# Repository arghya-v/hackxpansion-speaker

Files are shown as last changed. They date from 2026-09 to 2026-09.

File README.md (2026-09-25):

# hackxpansion Speaker Module

**Crates:** pkg:cargo/hackxpansion_speaker@0.1.0
<br/>
A speaker module for hackxpansion that allows sound to be emitted from the device

The module takes digital audio from the Hackxpansion controller, converts it to an analog signal, amplifies it, and drives a speaker
## Images
case
pcb

## Schematic
schematic
## Overview

The Speaker Module provides the HackXpansion system with a dedicated audio output.

```text
                    Hackxpansion Controller
                              │
                              │
                    ┌─────────┴─────────┐
                    │    Digital Audio  │
                    │                   │
                    └─────────┬─────────┘
                              │
                              ▼
                    ┌───────────────────┐
                    │  TLV320DAC3100    │
                    │    Audio DAC      │
                    └─────────┬─────────┘
                              │
                              │ Analog Audio
                              ▼
                    ┌───────────────────┐
                    │      PAM8320      │
                    │  Class-D Amplifier│
                    └─────────┬─────────┘
                              │
                              ▼
                         ┌─────────┐
                         │ Speaker │
                         └─────────┘
```

The controller sends digital audio to the module over I²S. The TLV320DAC3100 converts the digital signal into analog audio, which is then amplified by the PAM8320 before being sent to the speaker.

## Features
* 48 kHz, 16-bit audio
* Two user-input buttons

## Hardware

The **TLV320DAC3100** converts the incoming digital I²S stream into an analog audio signal.

It is configured for:

```text
Sample Rate: 48 kHz
Bit Depth:   16-bit
Interface:   I²S
MCLK:        12.288 MHz
```

The DAC is controlled over I²C and has a dedicated hardware reset line.

The analog output from the DAC is passed to a **PAM8320 Class-D amplifier**.

## Module Interface

The module uses the HackXpansion GPIO bank for both audio and user input.

| GPIO  | Function  |
| ----- | --- |
| GPIO0 | I²C SCL |
| GPIO1 | I²C SDA |
| GPIO2 | I²S BCLK  |
| GPIO3 | I²S DIN |
| GPIO4 | I²S LRCLK |
| GPIO5 | MCLK |
| GPIO6 | DAC RESET |
| GPIO7 | Button 1  |
| GPIO8 | Button 2  |
| GPIO9 | Unused |

See the [Xpanse API docs](https://docs.rs/xpanse-api/latest/xpanse_api/index.html)

This allows the main HackXpansion firmware to assign functionality to the buttons without the speaker module needing to know what those actions are.

The driver is responsible for:

1. Resetting the audio DAC
2. Configuring the DAC over I²C
3. Starting the master clock
4. Starting the I²S output
5. Registering the audio interface with HackXpansion
6. Registering the module buttons

`lib.rs` contains the HackXpansion-specific module driver, while `dac.rs` contains the reusable TLV320DAC3100 driver.

---

This was all possible thanks to [Hackspansion: A hackclub YSWS](http://hackxpansion.hackclub.com/)

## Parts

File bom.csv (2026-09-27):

Designator | Footprint | Quantity | Value | LCSC Part #
C1 | C155422_C0402 | 1 | 100nF | C155422
C2, C3, C4, C5, C7 | C15850_C0805 | 5 | 10 µF | C15850
J1 | Male_Module | 1 | ~
LS1 | SPKR_CMS-15113-078S | 1 | CMS-15113-078S
R1 | 0805 | 1 | 1k
R2 | 0805 | 1 | 68k
R3, R4 | 0805 | 2 | 10k
SW1, SW2 | SW_PUSH_6mm | 2 | SW_Push
U1 | C179677_LFCSP-32_L5_0-W5_0-P0_50-BL-EP | 1 | TLV320DAC3100IRHBR | C179677
U2 | C113367_MSOP-8_L3_0-W3_0-P0_65-LS5_0-BL | 1 | PAM8302AASCR | C113367

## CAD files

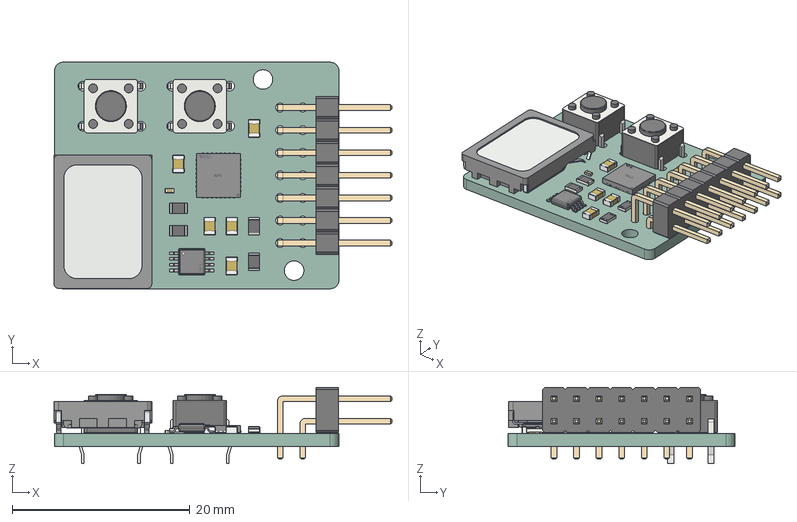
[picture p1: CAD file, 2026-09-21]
Bluetooth Mod.step
38.0 x 25.5 x 8.58 mm
C0805_L2.0-W1.3-H1.3 x 5
CUI_DEVICES_CMS-15113-078S
C0402_L1.0-W0.5-H0.5
R_0805_2012Metric x 4
PinHeader_2x07_P254mm_Horizontal
MSOP-8_L3.0-W3.0-P0.65-LS5.0-BL
LFCSP-32_L5.0-W5.0-H0.8-P0.50
SW_PUSH_6mm x 2
BluDF65_PCB

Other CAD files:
speaker module.f3z

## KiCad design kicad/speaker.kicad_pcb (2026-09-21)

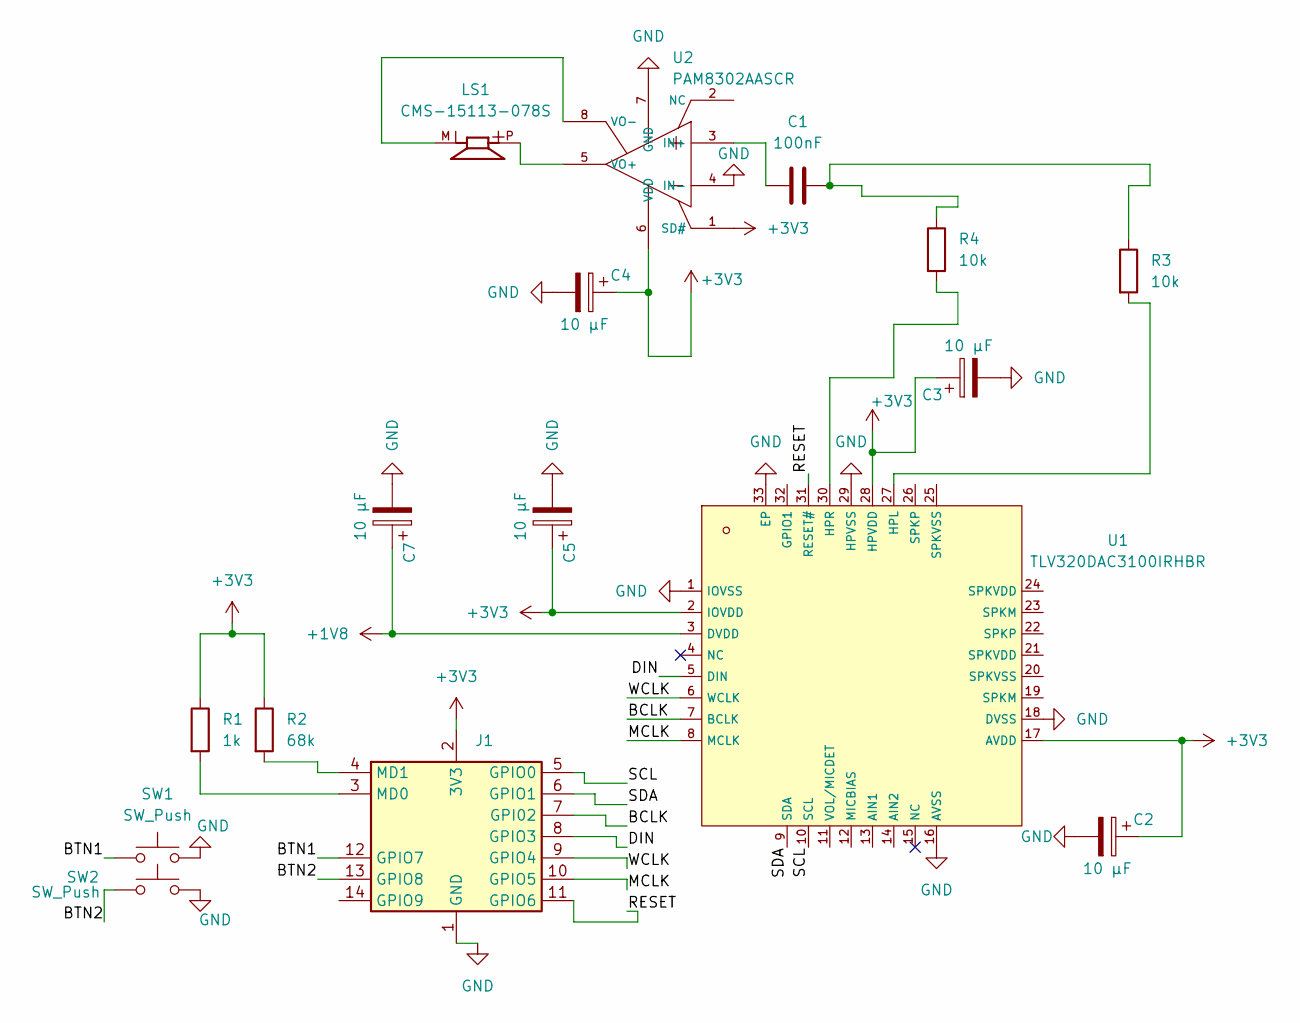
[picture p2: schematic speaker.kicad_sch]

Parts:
C1: 100nF; C155422_C0402
C2, C3, C4, C5, C7: 10 µF; C15850_C0805
J1: Male_Module
LS1: CMS-15113-078S; SPKR_CMS-15113-078S; PARTREV 1
R1: 1k; R_0805_2012Metric_Pad1.20x1.40mm_HandSolder
R2: 68k; R_0805_2012Metric_Pad1.20x1.40mm_HandSolder
R3, R4: 10k; R_0805_2012Metric_Pad1.20x1.40mm_HandSolder
SW1, SW2: SW_Push; SW_PUSH_6mm
U1: TLV320DAC3100IRHBR; C179677_LFCSP-32_L5_0-W5_0-P0_50-BL-EP; LCSC C179677
U2: PAM8302AASCR; C113367_MSOP-8_L3_0-W3_0-P0_65-LS5_0-BL; LCSC C113367

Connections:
+1V8: C7.1, U1.3 (DVDD)
+3V3: C2.1, C3.1, C4.1, C5.1, J1.2 (3V3), R1.1, R2.1, U1.2 (IOVDD), U1.17 (AVDD), U1.28 (HPVDD), U2.1 (SD#), U2.6 (VDD)
/BCLK: J1.7 (GPI02), U1.7 (BCLK)
/BTN1: J1.12 (GPIO7), SW1.1
/BTN2: J1.13 (GPIO8), SW2.1
/DIN: J1.8 (GPIO3), U1.5 (DIN)
/MCLK: J1.10 (GPIO5), U1.8 (MCLK)
/RESET: J1.11 (GPIO6), U1.31 (RESET#)
/SCL: J1.5 (GPIO0), U1.10 (SCL)
/SDA: J1.6 (GPIO1), U1.9 (SDA)
/WCLK: J1.9 (GPIO4), U1.6 (WCLK)
GND: C2.2, C3.2, C4.2, C5.2, C7.2, J1.1 (GND), SW1.2, SW2.2, U1.1 (IOVSS), U1.16 (AVSS), U1.18 (DVSS), U1.29 (HPVSS), U1.33 (EP), U2.4 (IN-), U2.7 (GND)
unnamed: C1.2, R3.1, R4.1
unnamed: J1.3 (MD0), R1.2
unnamed: J1.4 (MD1), R2.2
unnamed: R3.2, U1.27 (HPL)
unnamed: R4.2, U1.30 (HPR)
unnamed: C1.1, U2.3 (IN+)
unnamed: LS1.P, U2.5 (VO+)
unnamed: LS1.M, U2.8 (VO-)

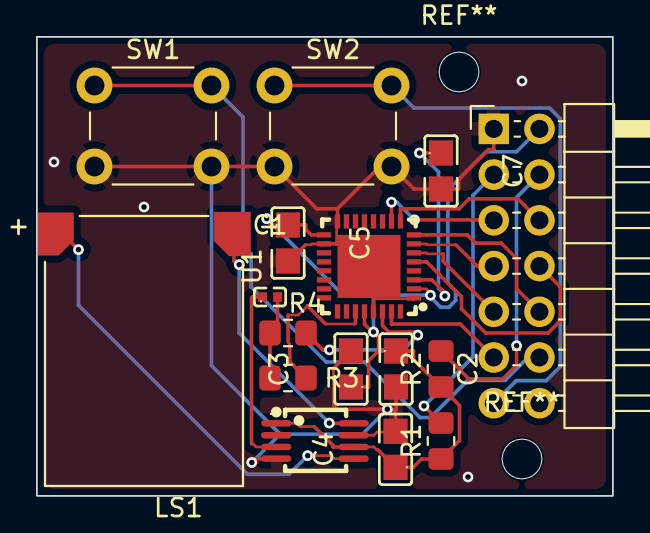
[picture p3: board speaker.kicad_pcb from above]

Board: 2 copper layers, 32.0 x 25.5 mm, 16 parts (0 on the bottom side), 20 nets.

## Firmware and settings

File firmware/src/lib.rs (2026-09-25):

#![no_std]

pub mod dac;

use embassy_rp::{
    dma,
    gpio::{Level, Output},
    interrupt::typelevel::{Binding, DMA_IRQ_0},
    peripherals::DMA_CH0,
    pio_programs::{
        clk::{PioClk, PioClkProgram},
        i2s::{PioI2sOut, PioI2sOutProgram},
    },
};

use xpanse_api::{
    with_pio,
    bus::allocator::BusAllocator,
    driver::{Driver, DriverError, DriverMeta},
    gpio_bank::{BankPins, GpioBank},
    interfaces::buttons::{
        pin_button,
        A,
        B,
    },
    metadata::{
        ModuleDetectResistor,
        ModuleID,
        ModuleSlot,
    },
    registry::Registry,
};

const SAMPLE_RATE: u32 = 48_000;
const BIT_DEPTH: u32 = 16;
const MCLK_FREQUENCY: u32 = 12_288_000;

#[derive(Copy, Clone)]
pub struct AudioDmaIrqs;

unsafe impl Binding<DMA_IRQ_0, dma::InterruptHandler<DMA_CH0>> for AudioDmaIrqs {}

pub struct SpeakerDriver;

impl DriverMeta for SpeakerDriver {
    const ID: ModuleID = ModuleID {
        md0: ModuleDetectResistor::R1K,
        md1: ModuleDetectResistor::R68K,
    };
}

impl<G> Driver<G> for SpeakerDriver
where
    G: BankPins,
{
    async fn create(
        bank: GpioBank<G>,
        slot: ModuleSlot,
        registry: &mut Registry,
        buses: &mut BusAllocator,
    ) -> Result<(), DriverError> {

        let mut reset = Output::new(
            bank.gpio6,
            Level::Low,
        );

        embassy_time::Timer::after_millis(5).await;

        reset.set_high();

        embassy_time::Timer::after_millis(10).await;

        core::mem::forget(reset);

        let mut i2c_bus = buses
            .create_i2c_bitbang(
                bank.gpio0,
                bank.gpio1,
                400_000,
            )
            .map_err(|_| DriverError::InitFailed)?;

        dac::reset(&mut i2c_bus).await?;

        dac::configure(&mut i2c_bus).await?;

        registry.register(
            slot,
            Self::ID,
            pin_button::<A>(
                bank.gpio7.into(),
            ),
        );

        registry.register(
            slot,
            Self::ID,
            pin_button::<B>(
                bank.gpio8.into(),
            ),
        );

        let dma = buses
            .request_dma::<DMA_CH0>()
            .map_err(|_| DriverError::InitFailed)?;

        let mclk_pio = buses
            .request_pio(&[
                &bank.gpio5,
            ])
            .ok_or(DriverError::InitFailed)?;

        with_pio!(
            mclk_pio,
            mclk_common,
            mclk_sm,
            {
                let mclk_program = PioClkProgram::new(
                    &mut *mclk_common,
                );

                let mut mclk = PioClk::new(
                    &mut *mclk_common,
                    mclk_sm,
                    bank.gpio5,
                    &mclk_program,
                    MCLK_FREQUENCY,
                );

                mclk.start();

                core::mem::forget(mclk);
            }
        );

        let i2s_pio = buses
            .request_pio(&[
                &bank.gpio2,
                &bank.gpio3,
                &bank.gpio4,
            ])
            .ok_or(DriverError::InitFailed)?;

        with_pio!(
            i2s_pio,
            i2s_common,
            i2s_sm,
            {
                let i2s_program = PioI2sOutProgram::new(
                    &mut *i2s_common,
                );

                let mut i2s = PioI2sOut::new(
                    &mut *i2s_common,
                    i2s_sm,
                    dma,
                    AudioDmaIrqs,
                    bank.gpio3,
                    bank.gpio2,
                    bank.gpio4,
                    SAMPLE_RATE,
                    BIT_DEPTH,
                    &i2s_program,
                );

                i2s.start();

                registry.register(
                    slot,
                    Self::ID,
                    i2s,
                );
            }
        );

        Ok(())
    }
}

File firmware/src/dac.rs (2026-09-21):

use embassy_time::Timer;
use embedded_hal_async::i2c::I2c;

use xpanse_api::driver::DriverError;

const DAC_ADDRESS: u8 = 0x18;

async fn write_register<I>(
    i2c: &mut I,
    register: u8,
    value: u8,
) -> Result<(), DriverError>
where
    I: I2c,
{
    i2c.write(
        DAC_ADDRESS,
        &[register, value],
    )
    .await
    .map_err(|_| DriverError::InitFailed)
}

pub async fn reset<I>(
    i2c: &mut I,
) -> Result<(), DriverError>
where
    I: I2c,
{
    write_register(i2c, 0x00, 0x00).await?;

    write_register(i2c, 0x01, 0x01).await?;

    Timer::after_millis(10).await;

    Ok(())
}

pub async fn configure<I>(
    i2c: &mut I,
) -> Result<(), DriverError>
where
    I: I2c,
{
    
    write_register(i2c, 0x00, 0x00).await?;
    write_register(i2c, 0x04, 0x00).await?;
    // NDAC = 1, powered
    write_register(i2c, 0x0B, 0x81).await?;
    // MDAC = 2, powered
    write_register(i2c, 0x0C, 0x82).await?;
    // DOSR = 128
    write_register(i2c, 0x0D, 0x00).await?;
    write_register(i2c, 0x0E, 0x80).await?;
    write_register(i2c, 0x1B, 0x00).await?;
    write_register(i2c, 0x1C, 0x00).await?;
    write_register(i2c, 0x3C, 0x0B).await?;
    write_register(i2c, 0x00, 0x08).await?;
    write_register(i2c, 0x01, 0x04).await?;
    write_register(i2c, 0x00, 0x00).await?;
    write_register(i2c, 0x74, 0x00).await?;
    write_register(i2c, 0x00, 0x01).await?;
    write_register(i2c, 0x1F, 0x04).await?;
    write_register(i2c, 0x21, 0x4E).await?;
    write_register(i2c, 0x23, 0x44).await?;
    write_register(i2c, 0x28, 0x06).await?;
    write_register(i2c, 0x29, 0x06).await?;
    write_register(i2c, 0x1F, 0xC2).await?;
    // HPL analog volume = -9 dB
    write_register(i2c, 0x24, 0x92).await?;
    // HPR analog volume = -9 dB
    write_register(i2c, 0x25, 0x92).await?;
    write_register(i2c, 0x00, 0x00).await?;
    write_register(i2c, 0x3F, 0xD4).await?;
    write_register(i2c, 0x41, 0xD4).await?;
    // DAC right digital gain.
    write_register(i2c, 0x42, 0xD4).await?;
    // Unmute left + right DAC.
    write_register(i2c, 0x40, 0x00).await?;
    Timer::after_millis(20).await;

    Ok(())
}

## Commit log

2026-09-21 done driver
2026-09-21 Rename Bluetooth Mod.kicad_pcb to kicad/speaker.kicad_pcb
    [speaker.kicad_pcb]
2026-09-21 Rename Bluetooth Mod.kicad_prl to kicad/speaker.kicad_prl
2026-09-21 Rename Bluetooth Mod.kicad_pro to kicad/speaker.kicad_pro
2026-09-21 Rename Bluetooth Mod.kicad_sch to kicad/speaker.kicad_sch
    [speaker.kicad_sch]
2026-10-04 Update bom.csv to include pricing details
    Added price information for components and total costs.
2026-10-11 Add 3D PCB image to README
    Add a 3D PCB image to the README.
2026-10-11 Rename speaker module.f3z to CAD/speaker module.f3z
2026-10-11 Add CAD files
2026-10-11 Revise BOM with updated values and part numbers
    Updated component values and part numbers in BOM.
